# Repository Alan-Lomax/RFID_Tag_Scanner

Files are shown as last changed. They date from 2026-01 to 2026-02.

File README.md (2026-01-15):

# RFID_Tag_Scanner
This is a self contained "appliance" that can be used for testing ISO15693 RFID tags and optionally
subscribing to an MQTT broker to monitor any published messages (which might not be RFID related).

RFID input is via a PN5180-NFC scanner board. Output is via a color TFT screen (Output is also mirrored on a web page).
For Initial setup this device sets up its own Access Point hotspot. 
Pointing a web browser at it allows for it to be configured further. (see readme for details)

## Parts List (one of each):
ESP32 DevKit 1 case  .... plus 
2.8 inch TFT angled display box   ... plus 
PN5180-nfc   RFID tag reader board

## Usage
In use RFID tags can be placed on top and the LCD screen will indicate the tag details.

## 3-D Printed Project Box
This is a mash up of several 3D designs. When assembled it makes a desktop box that houses
an ESP32 in a compartment accessed from the bottom, a 2.8 inch color LCD screen in a front bezel,
and a PN5180 RFID scanner module hidden behind a top mounted cover plate.
All other wiring is contained in the box and only the USB connector is available as an external connection (for power). 

### The constituent designs used:
2.8" TFT ili9341 SPI Case     https://www.thingiverse.com/thing:3461768
ESP32 DevKit V1 Case (Thick)  https://www.thingiverse.com/thing:4609596

## 3D Case parts
Print one of each:
- Item 1 the modified box structure c/w ESP compartment        01 RFID_Scanner_RGB_Box_R0.6.stl
- Item 2 the unmodified LCD lid                                02 TFT_RGB_LCD_28_FRONT.STL
- Item 4 the lid for the ESP32 holder compartment in item 1    04 ESP32_Case_Lid

## And choose one of these to Print 
- Item 3a the modified LCD Lid adapted to mount the PN5180-NFC 03 PN5180-NFC_Cover.stl
- Item 3b An alternate for top mounting the PN5180-NFC         03b PN5180-NFC_Cover_TopMount.stl

# Print Notes:
The main box takes several hours to print. It has designed in supports that are easy to break away.
It is to be printed with the ESP cavity down against the print bed. (the top and front are open).
The other parts are less than an hour each to print and must be printed flat to the print bed.

The easy method for the PN5180-NFC is to attach it with hot glue to the top of the lid using the TopMount version of the lid.
The wires will protrude through the slot and down into the box.

Alternatively the original lid (03 PN5180-NFC_Cover.stl) for the PN5180-NFC has no openings and the PCB will mount
on the inside  of this lid ((again hot glue recommended but screws are also possible.)                 

That lid then attaches to the top of the box using 4 screws (3x10 mm)
The  LCD is 'sandwhiched' between the frony bezel and the box using 4 screws (3x10 mm)

## Wiring:
I used simple dupont F-F connectors.
The wiring could be done individually or in groups according to what you have on hand.
I had a 1o pin F-F cable and used that as a basis. At one end the 10 pin housing was kept 'stock' (LCD end) 
and at the other end the individual wires were removed and reinserted to change thw wire order.
Beyond that individual or multipin dupont housings were used according to what was on hand.
Wire Splices:
There are 4 signals that need splicing, one is 3.3 volt power and the other 3 are to do with SPI communications.

The 3.3volt output from the ESP32 needs to be split into 3 different wires, one goes to the 3 volt supply on the LCD, another 
goes to the backlight LED supply on the LCD, and the third goes to the 3.3 volt supply pin on the PN5180-NFC.
 
Because the SPI interface is used for both the LCD display and the PN5180-nfc the three wires
the three SPI wires (Clock, MISO, and MOSI) need to be split with one going to the LCD, and one to the RFID scanner board.

## Caution:
When sitting on the desk excessive downward presssure can activiate the reset button on the ESP32
You could elect to break away the cover over the reset button - making it a recessed button not subject to accidental activation.

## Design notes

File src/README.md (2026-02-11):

# MQTT RFID Reader/Display - ESP32 Version

Complete MQTT-enabled RFID reader with TFT display for ESP32.

## Version 1.0.15 - Production Ready

Optimized for RFID tag range testing with fast, responsive scanning and flicker-free display updates.

**Key Features:**
- **Fast scanning**: 250ms scan interval (4 scans/second)
- **Responsive display**: 500ms update rate with selective region updates (no flicker)
- **Quick detection**: Tag presence/removal detected within 500ms-1000ms
- **Modular architecture**: Clean separation of concerns across focused modules
- **Web configuration**: Easy setup via browser interface
- **MQTT integration**: Real-time tag event publishing
- **Security**: WiFi password protection, documented security considerations

**Core Modules:**
- `MQTTTagReaderDisplay_ESP32.ino` - Main application & coordination
- `nfc_reader.cpp/h` - PN5180 NFC interface (ISO15693 only)
- `display.cpp/h` - ILI9341 TFT display management (flicker-free updates)
- `web_server.cpp/h` - HTTP interface & configuration pages
- `mqtt_handler.cpp/h` - MQTT publishing & subscription
- `ILI9341_Landscape.h` - Custom landscape display class

## Hardware Requirements

- **ESP32** (WROOM-32 or compatible DevKit board)
- **PN5180 NFC Reader** (ISO15693/SLIX2 compatible)
- **ILI9341 TFT Display** (240x320, 2.8" or 3.2")
- Jumper wires
- USB cable for programming
- 3.3V and 5V power (from ESP32)

## Wiring

### PN5180 NFC Reader
```
PN5180 Pin    ESP32 Pin      Wire Color
-------------------------------------------
NSS (CS)   →  GPIO 5  (D5)   Orange
BUSY       →  GPIO 21 (D21)  Blue
RST        →  GPIO 22 (D22)  White
MOSI       →  GPIO 23 (D23)  Green
MISO       →  GPIO 19 (D19)  Purple
SCK        →  GPIO 18 (D18)  Brown
3.3V       →  3V3            Red
5V         →  VIN            ** CRITICAL! **
GND        →  GND            Black
```

**IMPORTANT:** The PN5180 needs **5V on the TVDD pin** (via the 5V/VIN connection) for the RF transmitter to work properly. The 3.3V connection powers the digital section.

For more information see: https://easyelecmodule.com/pn5180-explained-the-ultimate-nfc-module-with-full-protocol-compatibility/

### ILI9341 TFT Display
```
Display Pin   ESP32 Pin
---------------------------
CS         →  GPIO 15 (D15)
RST        →  GPIO 4  (D4)
DC         →  GPIO 2  (D2)
MOSI       →  GPIO 23 (D23) - shared with PN5180
MISO       →  GPIO 19 (D19) - shared with PN5180
SCK        →  GPIO 18 (D18) - shared with PN5180
VCC        →  3V3
GND        →  GND
LED        →  3V3 (or PWM pin for brightness control)
```

## Library Requirements

Install these libraries via Arduino Library Manager:

1. **PN5180 Library** by tueddy
   - GitHub: https://github.com/tueddy/PN5180-Library
   - Download ZIP and install via: Sketch → Include Library → Add .ZIP Library

2. **Adafruit GFX Library**
   - Tools → Manage Libraries → Search "Adafruit GFX"

3. **Adafruit ILI9341**
   - Tools → Manage Libraries → Search "Adafruit ILI9341"

4. **PubSubClient** (MQTT)
   - Tools → Manage Libraries → Search "PubSubClient"

5. **ArduinoJson**
   - Tools → Manage Libraries → Search "ArduinoJson"

## Arduino IDE Setup

1. **Install ESP32 Board Support:**
   - File → Preferences
   - Additional Board Manager URLs: 
     ```
     https://dl.espressif.com/dl/package_esp32_index.json
     ```
   - Tools → Board → Boards Manager
   - Search "ESP32" → Install "ESP32 by Espressif Systems"

2. **Select Board:**
   - Tools → Board → ESP32 Arduino → "ESP32 Dev Module"

3. **Configure Upload Settings:**
   - Upload Speed: 921600
   - Flash Frequency: 80MHz
   - Partition Scheme: "Default 4MB with spiffs"

## Configuration

### First Boot

1. Power on the ESP32
2. Look for WiFi network named `ESP32-RFID-ReaderDisplay`
3. Connect to it with your phone/computer
4. Browser will open automatically, or go to: `192.168.4.1`
5. Enter your WiFi credentials and MQTT broker details

### Web Interface

After WiFi is configured, access the web interface at: `http://[device-ip]/`

**Pages:**
- `/` - Main status page (tag detection, statistics, MQTT history)
- `/config` - Configuration page (WiFi password not exposed)
- `/status` - JSON API endpoint

### Configuration Options

**WiFi Settings:**
- SSID: Your WiFi network name
- Password: WiFi password (stored securely, not displayed in web interface)

**MQTT Settings:**
- Broker: IP address of your MQTT broker
- Port: Usually 1883
- Base Topic: Base topic for all messages (default: `rfid`)
- Subscribe Topic: Topic pattern to receive messages (default: `rfid/#`)
- Sensor ID: Unique ID for this reader (1-255)

**Topics Published:**
- `[base]/Read` - When tag is first detected
- `[base]/Unread` - When tag is removed
- `[base]/Continuing` - Published once when tag remains present (after 3 seconds)

**Message Format (JSON - shortened field names):**
```json
{
  "u": "E004010918485391",
  "s": 33,
  "R": "R"
}
```
- `u` = UID
- `s` = sensor_id
- `R` = direction (R=Read, C=Continuing, U=Unread)

## Usage

### Normal Operation

1. Power on device
2. Display shows "Scanning..."
3. Place ISO15693 tag on PN5180 antenna
4. Display shows "TAG PRESENT" with UID
5. MQTT message published to configured topics
6. Remove tag to generate "Unread" event

### Display Information

**Upper Section - Local Tag Scanner:**
- Current tag status (Scanning... or Local Tag Read)
- Tag UID when present (16 characters)

**Middle Section - MQTT Broker Messages:**
- Last 4 MQTT messages from any sensor
- Color-coded by event type: Green (Read), Yellow (Continuing), Red (Unread)
- Shows sensor ID, UID, and direction

**Lower Section - Status:**
- Configuration URL
- PN5180 status, version, and protocol
- Scan statistics (Scans, OK, Fail counts with real-time updates)
- MQTT connection status and broker info
- Topic configuration

**Display Features:**
- Flicker-free updates (selective region redrawing)
- Fast refresh rate (500ms)
- Left-justified welcome screen
- Streamlined WiFi connection status

## Troubleshooting

### PN5180 Not Detecting Tags

**Check wiring:**
- Verify all SPI connections (MOSI, MISO, SCK)
- **Ensure 5V is connected to VIN** (CRITICAL!)
- NSS on GPIO 5
- BUSY on GPIO 21
- RST on GPIO 22

**Verify power:**
- Measure 3.3V on PN5180 3.3V pin
- Measure 5V on PN5180 5V pin
- Both should be present simultaneously

**Test tags:**
- Use ISO15693 compatible tags (SLIX, SLIX2, I-CODE, etc.)
- Some generic tags may not work
- Try multiple tags to rule out tag issues

### Display Not Working

- Check CS pin (GPIO 15)
- Verify DC pin (GPIO 2)
- Check RST pin (GPIO 4)
- Ensure shared SPI pins are correct
- Try different display rotation: `tft.setRotation(1)` or `tft.setRotation(3)`

### WiFi Connection Issues

- Device creates AP named `ESP32-RFID-ReaderDisplay`
- Connect and configure via 192.168.4.1
- Check credentials carefully
- 2.4GHz WiFi only (ESP32 doesn't support 5GHz)

### MQTT Not Connecting

- Verify broker IP address is correct
- Check port (default 1883)
- Ensure broker accepts connections from this IP
- Check firewall settings
- Monitor MQTT broker logs

### Compilation Errors

**"PN5180.h: No such file"**
- Install tueddy's PN5180 library from GitHub

**"Adafruit_ILI9341.h: No such file"**
- Install Adafruit ILI9341 library via Library Manager

**"PubSubClient.h: No such file"**
- Install PubSubClient library via Library Manager

## Serial Monitor Debug

Connect via USB and open Serial Monitor (115200 baud) to see:
- Initialization status
- Tag detection events
- MQTT connection status
- Configuration details
- Error messages

## Performance

- **Scan Rate:** 250ms per scan (4 scans/second)
- **Tag Detection:** ~500ms (requires 2 consecutive reads for noise filtering)
- **Tag Removal:** ~1000ms timeout (4 missed scans)
- **Display Update:** Every 500ms (flicker-free selective updates)
- **MQTT Publish:** <100ms per message

**Optimized for Range Testing:**
The fast scan and display rates make this ideal for sliding RFID tags on a jig to determine detection range boundaries with precision.

## Known Issues & Limitations

1. **PN5180 requires 5V on TVDD** - Without this, RF transmitter won't work
2. **ISO15693 only** - ISO14443 (MIFARE) tags not currently supported
3. **Single tag detection** - Anti-collision not implemented
4. **No MQTT encryption** - Messages sent in plain text (see SECURITY.md)
5. **No web authentication** - Web interface accessible to anyone on network (see SECURITY.md)

**See SECURITY.md for security considerations and mitigation strategies.**

## Technical Details

### Critical PN5180 Setup

The PN5180 initialization sequence is critical:

```cpp
nfc.begin();        // Initialize SPI
nfc.reset();        // Reset chip
nfc.setupRF();      // Configure for ISO15693

// Then in loop:
nfc.getInventory(uid);  // Just scan, no reset/setupRF!
```

**DO NOT** call `reset()` or `setupRF()` in the loop - only in setup()!

### Power Requirements

- ESP32: ~240mA typical
- PN5180: ~150mA during RF transmission (from 5V rail)
- Display: ~100mA with backlight
- **Total:** ~500mA minimum

Use a quality USB power supply capable of delivering at least 1A.

## Important Files

- **README.md** - This file (setup, wiring, troubleshooting)
- **SECURITY.md** - Security considerations and best practices
- **REFACTORING_SUMMARY.md** - Details on modular architecture

## Support

For issues, check:
1. **README.md** - Wiring diagram and basic troubleshooting
2. **SECURITY.md** - Security considerations for your deployment
3. Serial Monitor output (115200 baud) for error messages
4. Web interface `/status` endpoint for diagnostics

**Common Issues:**
- Tags not detected → Check 5V connection to PN5180 VIN
- Display flickering → Already fixed in v1.0.5+
- Slow response → Update to v1.0.8+ for fast scanning
- WiFi password exposed → Fixed in v1.0.15

## License

MIT License - Free to use and modify

## Version History

### 1.0.15 - Security & Final Polish (Current)
- **Security Fix:** WiFi password no longer exposed in web interface HTML
- Added SECURITY.md with vulnerability assessment and mitigation strategies
- Password field now uses placeholder instead of displaying actual password

### 1.0.14 - MQTT Optimization
- Fixed redundant "Continuing" messages - only published once per continuous detection
- Added last event tracking to prevent MQTT spam

### 1.0.13 - Continuing Messages
- Fixed callback logic to enable "Continuing" message publishing
- Callback now triggered on every scan when tag is present

### 1.0.12 - MQTT Display Updates
- Fixed MQTT history display not updating when buffer full
- Implemented sequence counter for reliable change detection
- MQTT messages now update display within 500ms

### 1.0.11 - Display Spacing
- Adjusted scan statistics number positioning (+6 pixels right)
- Improved visual spacing between colons and values

### 1.0.10 - Tag Removal Responsiveness
- Reduced TAG_TIMEOUT from 3000ms to 1000ms
- Tag removal now detected within 1 second (4 missed scans)
- Added comprehensive timing documentation

### 1.0.9 - Display Responsiveness
- Reduced display update interval from 2000ms to 500ms (4x faster)
- Display now updates every 500ms for immediate visual feedback
- Added timing configuration documentation

### 1.0.8 - Scan Speed Optimization
- Reduced scan interval from 500ms to 250ms (2x faster)
- Now scans 4 times per second for precise range testing

### 1.0.7 - Display Polish
- Streamlined WiFi boot sequence (single page, updates in place)
- Left-justified welcome screen for cleaner appearance
- Improved label positioning on scan statistics line

### 1.0.6 - Granular Display Updates
- Ultra-smooth scan statistics updates (numbers only, no flicker)
- Only redraws changed number fields, not entire status line

### 1.0.5 - Flicker-Free Display
- Implemented selective region updates (no more full screen redraws)
- Smart change detection for each display section
- Dramatically improved visual experience

### 1.0.4 - Spurious Detection Filter
- Implemented consecutive read requirement (2 reads minimum)
- Added robust filtering for false positive detections
- Eliminated ghost tag detection issues

### 1.0.3 - Ghost Tag Fix
- Fixed spurious tag readings when no tag present
- Enhanced UID validation (reject all-zeros and all-FF patterns)
- Added debounce logic for tag return detection

### 1.0.2 - Boot Stability
- Fixed spurious tag detection on boot with no tag present
- Added UID validation before processing

### 1.0.1 - Modular Architecture
- Separated web server functionality into web_server module
- Separated MQTT handling into mqtt_handler module
- Simplified main INO file for better maintainability
- ISO15693 single-protocol focus

### 1.0.0 - Initial Baseline
- ISO15693 scanning with PN5180
- Web interface with status and configuration
- MQTT publishing: Read, Continuing, Unread events
- Stable tag detection

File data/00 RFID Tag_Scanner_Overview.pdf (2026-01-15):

# RFID Tag Scanner

Alan Lomax (M8640)
MERG RFID Special Interest Group

Zoom Meeting #29

## Block Diagram

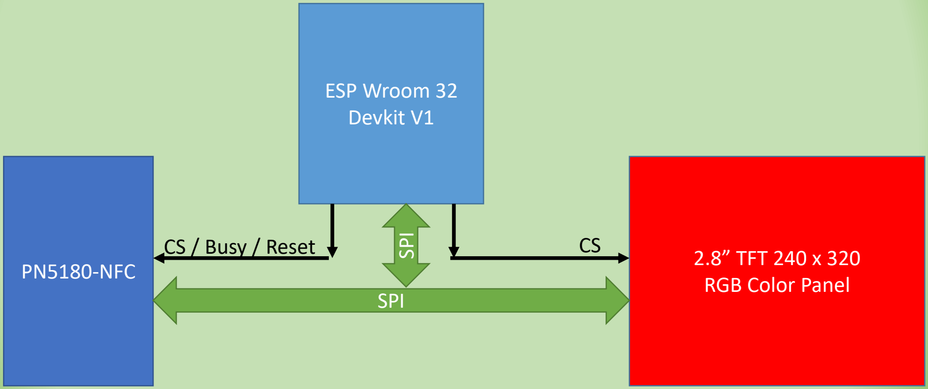
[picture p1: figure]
PN5180-NFC; ESP Wroom 32 Devkit V1; 2.8” TFT 240 x 320 RGB Color Panel; SPI; CS / Busy / Reset

## Block Diagram (Logical)

(2) Once on local WiFi unit will scan for RFID tags, update status numbers, and

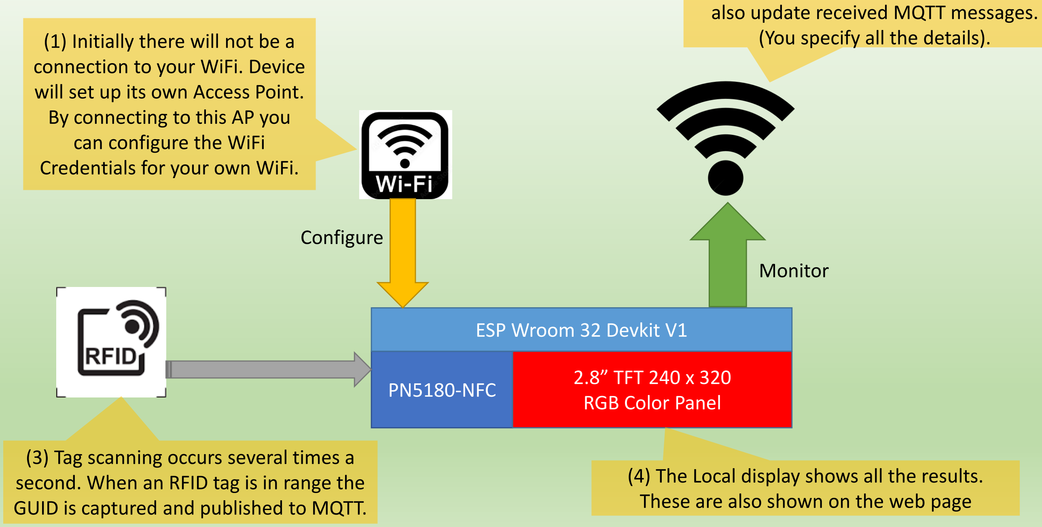
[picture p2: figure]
PN5180-NFC; ESP Wroom 32 Devkit V1; 2.8” TFT 240 x 320 RGB Color Panel; Configure; Monitor; (1) Initially there will not be a connection to your WiFi. Device will set up its own Access Point. By connecting to this AP you can configure the WiFi Credentials for your own WiFi.; also update received MQTT messages. (You specify all the details).; (3) Tag scanning occurs several times a; GUID is captured and published to MQTT.; These are also shown on the web page

second. When an RFID tag is in range the

(4) The Local display shows all the results.

## At this Moment

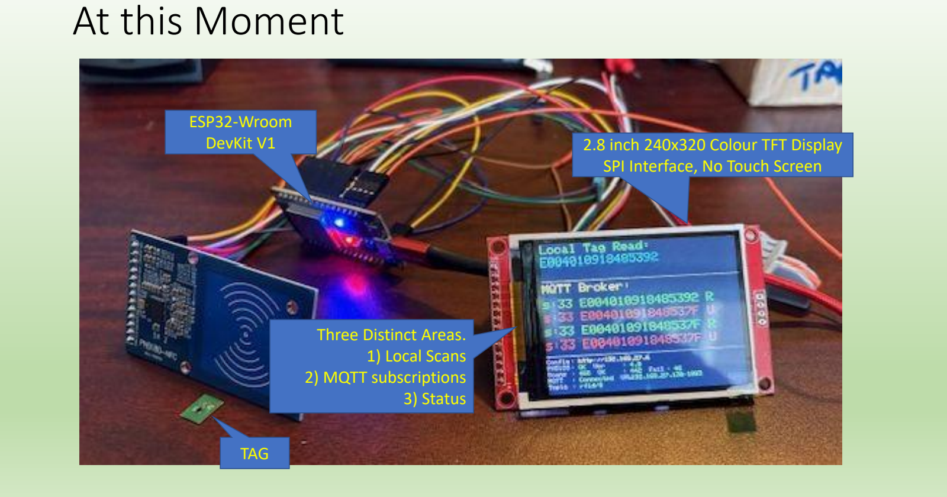
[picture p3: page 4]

TAG

PN5180-NFC

ESP32-Wroom
DevKit V1 | 2.8 inch 240x320 Colour TFT Display
| SPI Interface, No Touch Screen

Three Distinct Areas.
1) Local Scans
2) MQTT subscriptions
3) Status

## Web Interface (Main)

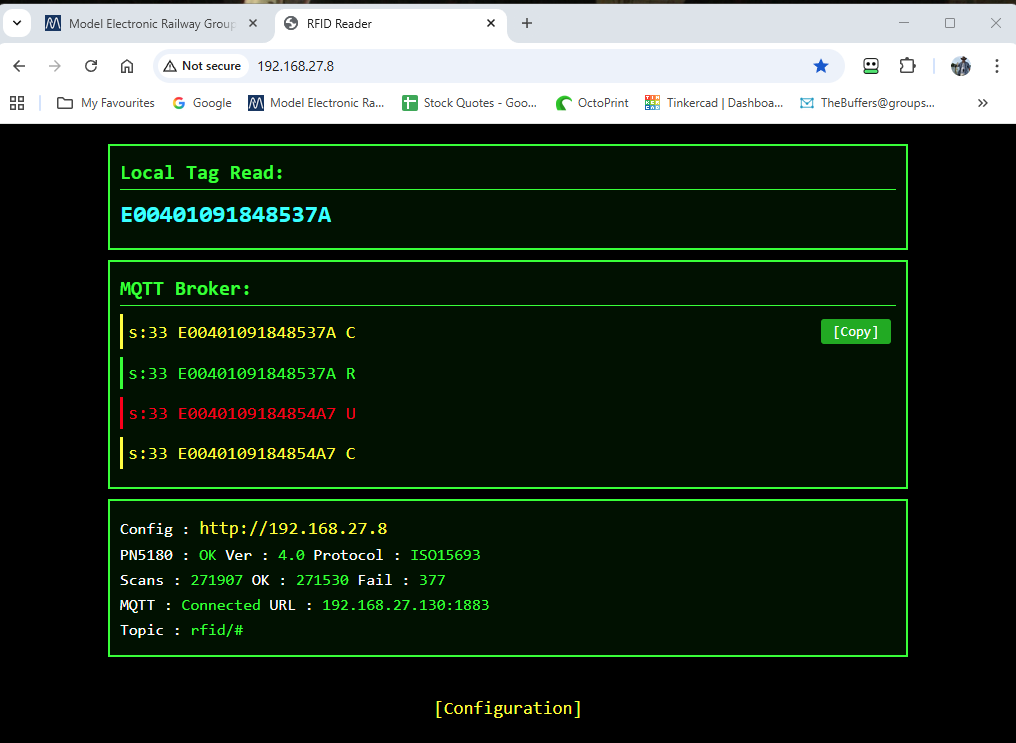
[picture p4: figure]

## Web Interface (Configuration)

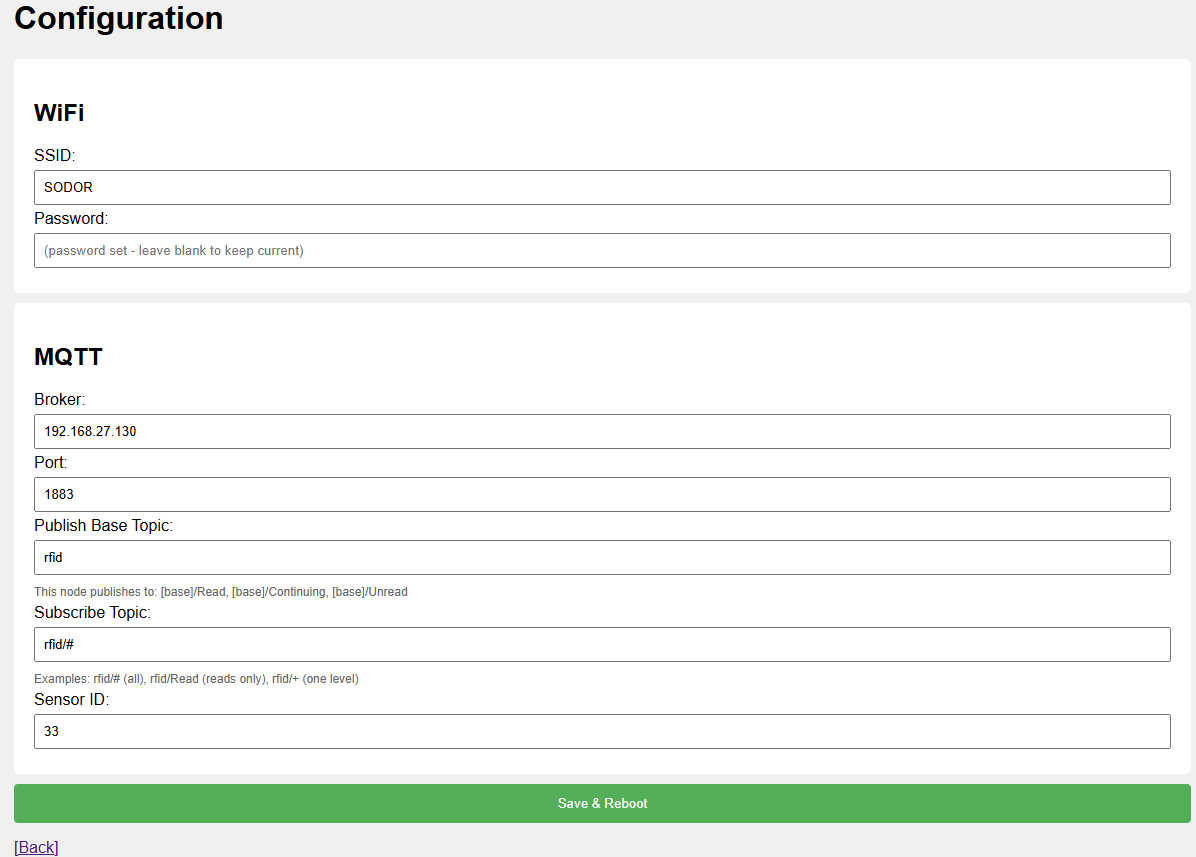
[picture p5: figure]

## Code Development

Previously I had developed a “Stock Ticker” display as an XMAS gift for my son in law. Reusable elements from this effort were expected to be:

1) ESP8266 Libraries
2) Local Display Interface Library
3) Web Interface Library
4) Initial Configuration and Remote Monitoring of Local Display
5) Saving and restoring data to and from Flash

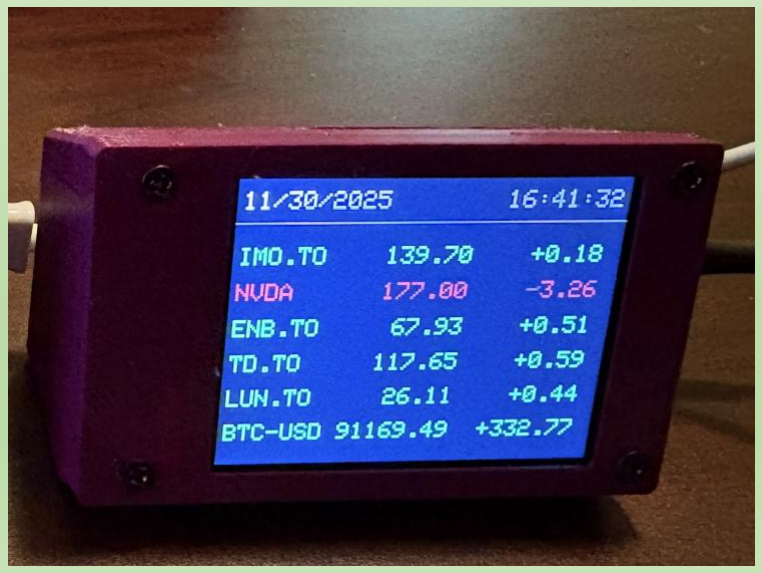
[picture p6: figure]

## Working with Claude (AI)

Reusing code from this project (provided) help me develop a well documented program for reading RFID tags using a PN5180-nfc module.
- {provide my pin assignment for this module}
- {detail how I wanted the code broken out into several modules}
- All of this was written up ahead of time (in NP++) and pasted into Claude’s window. Response was “Sure I can help you with that!”
- Needless to say it did not work first time. In fact it did not even compile
- Pasting the console output back into Claude quickly resolved compile issues. (Mostly variable scope and duplicate declarations)
- Then started working through the logic issues (Took several days).

## Summary of Issues

Hardware:
- Many internet sources claim do NOT mix 5V and 3v3 supplies on this module. Turned out to be bad advice. 5V drives the final RF amplifier. Message should have been do not mix Logic Levels (3V3 logic only)
- ESP8266 does not have enough available GPIO. (Moved to ESP32) Software
- Several libraries for this module are not fully implemented. Functions that should exist are merely stubs that return without doing anything.
- Local Display Update optimizations (flicker and update timing)
- Timing sequences when setting up scanning modes.
Logic
- “Ghost Tags” – UID’s being reported when no tags in range (cleanup).
- Scope Creep – adding features which while cool – distracted from goal

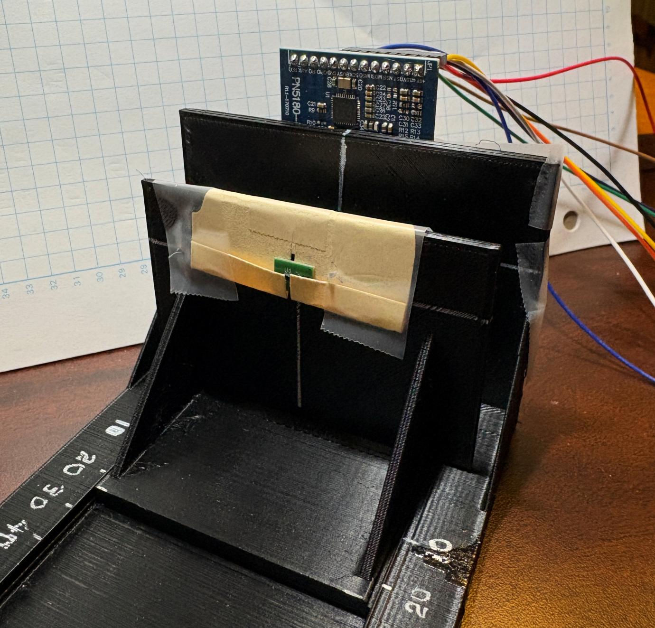
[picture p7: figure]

## In Use (Range Testing)

- Nick’s design of Test Jig
- Aerial is on fixed back plate
- Tag is on movable sled.(in pocket)
- Cross hairs for alignment
- Scale for distance
- Shown with PN5180-nfc
- Also tested SFR small aerial
- 55 tags .. Each tested twice

## 30 Second Video (Scanner In Use)

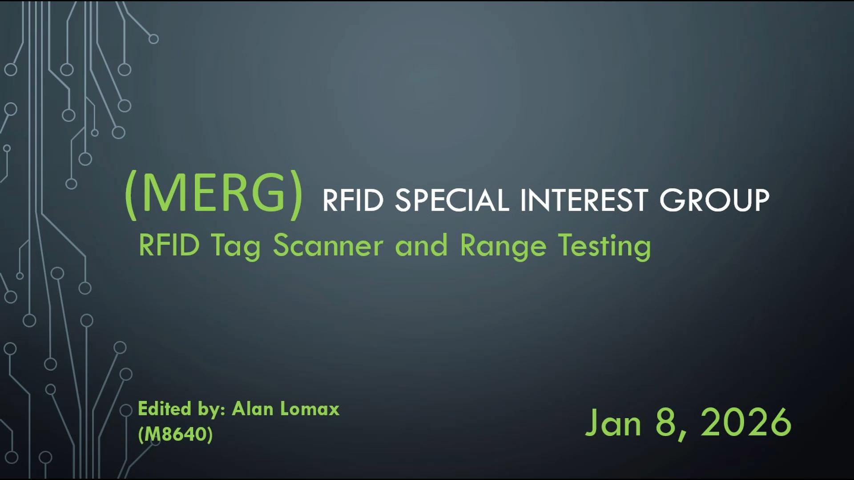
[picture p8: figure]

Play Me!

## Many Tags Were Built

Tags
- Each PCB RFID Tag was numbered (before assembly)
- Various values of matching capacitors were used
(43pF, 51pF, 53pF, 56pF, 62pF)
- Go / No-Go testing screened out defective tags (~5%) (build issues)
- Also 10 StaRFIshrail Rail ‘control’ tags were tested. (C unknown) Testing
- Drop tag into pouch on the sled part of the test jig
- Side it into and out of range. Intermittent reads did not count.
- At point where no read failures occurred the distance was recorded (along with the GUID)
After using the PN5180-nfc reader replace with a standard SFR aerial and repeat.

## Results

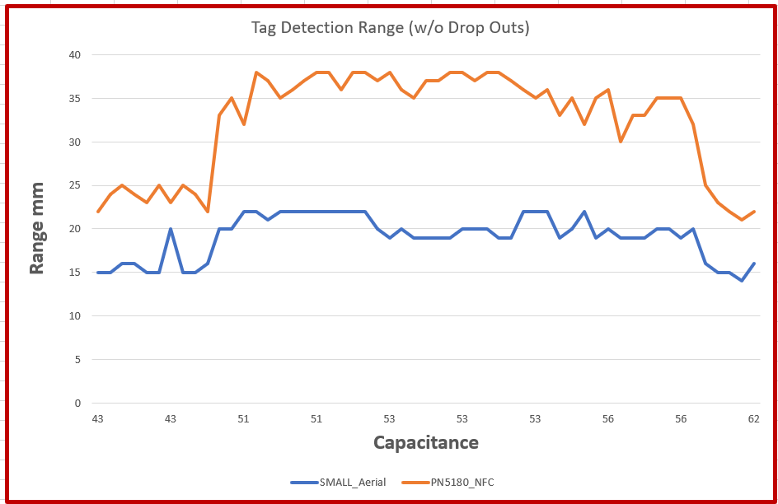
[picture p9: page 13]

# The End

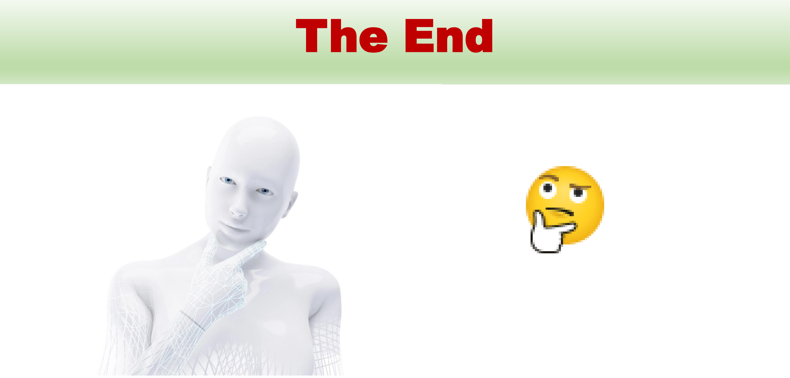
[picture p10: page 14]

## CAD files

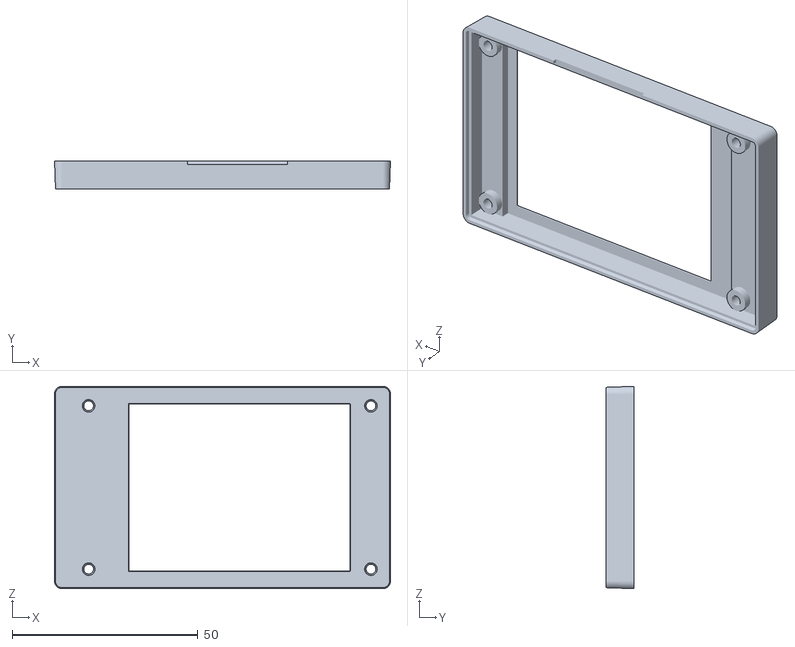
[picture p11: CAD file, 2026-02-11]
data/3D Printable Case/02 TFT_RGB_LCD_28_FRONT.STL
90.5 x 7.60 x 54.5

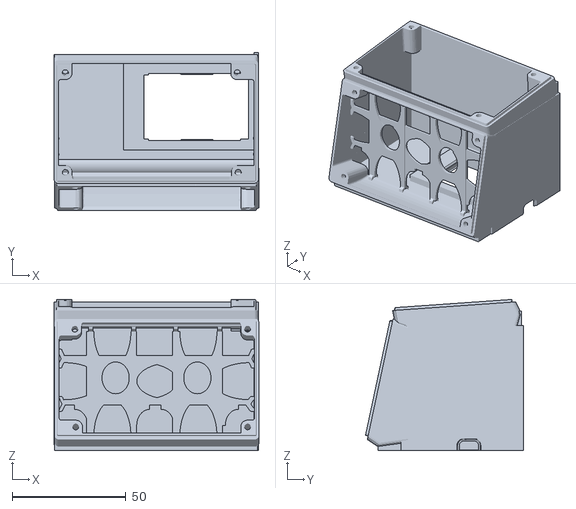
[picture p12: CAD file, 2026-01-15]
data/3D Printable Case/01 RFID_Scanner_RGB_Box_R0.6.stl
90.2 x 69.5 x 66.5

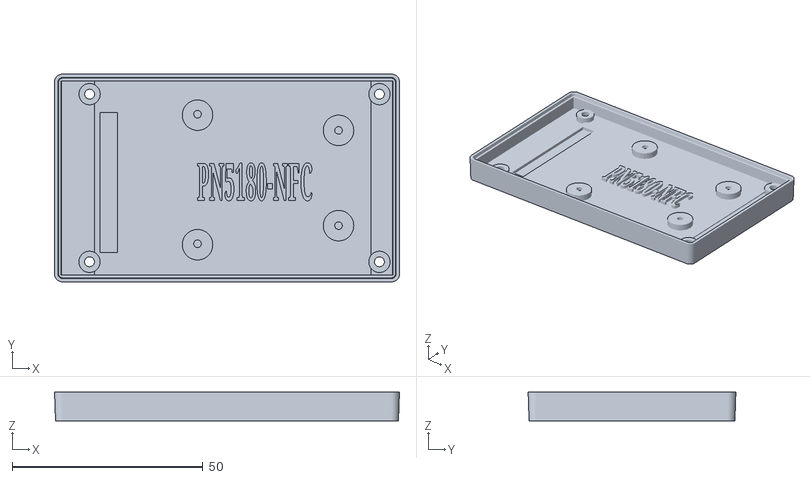
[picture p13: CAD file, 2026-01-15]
data/3D Printable Case/03 PN5180-NFC_Cover.stl
90.5 x 54.5 x 7.60

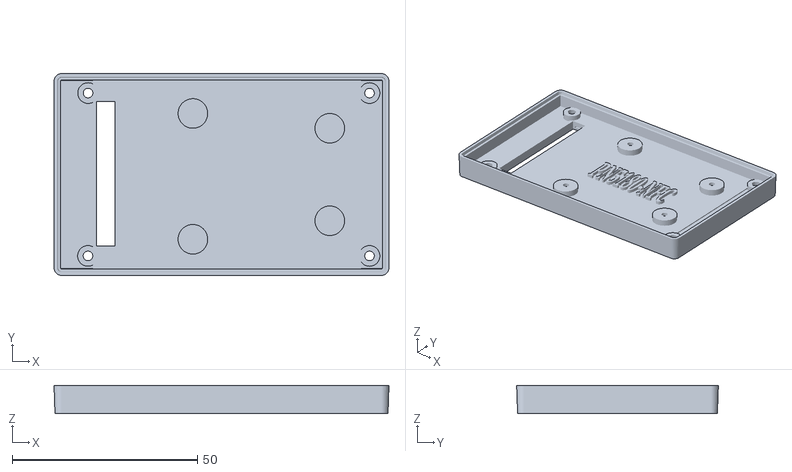
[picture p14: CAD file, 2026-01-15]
data/3D Printable Case/03b PN5180-NFC_Cover_TopMount.stl
90.5 x 54.5 x 7.60

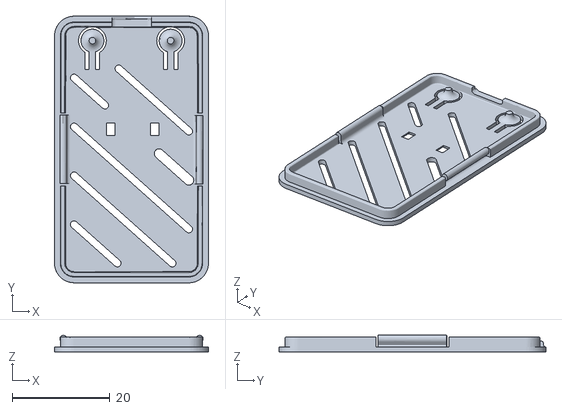
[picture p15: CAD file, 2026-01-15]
data/3D Printable Case/04 ESP32_Case_Lid.stl
31.5 x 54.6 x 3.39

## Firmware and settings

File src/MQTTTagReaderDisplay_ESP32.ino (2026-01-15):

/*
 * MQTT RFID Reader/Display - ESP32 Version (Modular)
 * 
 * ISO15693 Scanner 
 * - Looks for a Valid UID response and displays it on Local display.
 * - Also publishes to Web Page
 * - All scans published to an MQTT broker which you define.
 * 
 * Hardware:
 * - ESP32 (WROOM-32 or compatible)
 * - PN5180 NFC Reader (ISO15693)
 * - ILI9341 TFT Display (240x320)
 * 
 * See README.md for complete wiring and setup instructions
 */

#include <WiFi.h>
#include <WebServer.h>
#include <Preferences.h>
#include <PubSubClient.h>
#include <SPI.h>
#include "nfc_reader.h"
#include "display.h"
#include "web_server.h"
#include "mqtt_handler.h"

// Version Information
#define VERSION "1.0.15"
#define BUILD_DATE __DATE__
#define BUILD_TIME __TIME__
#define HOSTNAME "ESP32-RFID-ReaderDisplay"

// Timing Configuration
// =====================
// SCAN_INTERVAL (nfc_reader.h): 250ms = 4 scans/second
//   - Controls how often PN5180 checks for tags
//   - Lower = more responsive range detection
//   - Practical minimum: ~100ms (PN5180 RF field cycling)
//   - Consecutive reads required: 2 (noise filtering)
//
// TAG_TIMEOUT (nfc_reader.cpp): 1000ms
//   - How long after last detection before tag considered "removed"
//   - Should be 3-5x SCAN_INTERVAL for reliable detection
//   - Current: 4x scan interval = very responsive removal detection
//
// DISPLAY_UPDATE_INTERVAL: 500ms = 2 updates/second  
//   - Controls how often display refreshes
//   - With selective updates, can go much faster without flicker
//   - Practical minimum: ~100ms (human perception limit)
//   - Should be >= SCAN_INTERVAL for best responsiveness
//
// MQTT_RECONNECT_INTERVAL: 5000ms
//   - How often to retry MQTT connection if disconnected
//   - No need to change this
#define DISPLAY_UPDATE_INTERVAL 500
#define MQTT_RECONNECT_INTERVAL 5000

// Configuration
Config config;
Preferences preferences;

// Objects
WiFiClient espClient;
PubSubClient mqttClient(espClient);
WebServer webServer(80);

// State
unsigned long lastDisplayUpdate = 0;
unsigned long lastMqttReconnect = 0;
uint32_t mqttPublished = 0;
String lastPublishedUID = "";
String lastPublishedEvent = "";  // Track last event type (Read, Continuing, Unread)
unsigned long lastContinuingTime = 0;
#define CONTINUING_INTERVAL 3000  // Publish continuing every 3 seconds

// Forward declarations
void tagDetected(const char* uid, bool present);
void setupWiFi();
void loadConfig();
void saveConfig();

void setup() {
  Serial.begin(115200);
  delay(1000);
  
  Serial.println(F("\n================================="));
  Serial.println(F("  MQTT RFID Reader/Display"));
  Serial.print(F("  Version: ")); Serial.println(VERSION);
  Serial.print(F("  Build: ")); Serial.print(BUILD_DATE); 
  Serial.print(F(" ")); Serial.println(BUILD_TIME);
  Serial.println(F("  Platform: ESP32"));
  Serial.println(F("================================="));
  
  // Load configuration
  loadConfig();
  
  // Initialize SPI (shared between PN5180 and display)
  SPI.begin(18, 19, 23, 5);  // SCK, MISO, MOSI, SS
  Serial.println(F("SPI initialized"));
  
  // Initialize Display
  Serial.println(F("\n=== Initializing Display ==="));
  initDisplay();
  
  // Show welcome screen with version
  displayWelcome(VERSION, BUILD_DATE);
  delay(3000);  // Show for 3 seconds
  
  displayMessage("Initializing...");
  
  // Setup WiFi
  setupWiFi();
  
  // Setup MQTT
  initMqttHandler(&mqttClient, &config);
  
  // Pass broker config to display
  setMqttConfig(config.mqtt_broker, config.mqtt_port, config.mqtt_subscribe_topic);
  
  // Setup Web Server
  setWebServerConfig(&config);
  setWebServerMqttClient(&mqttClient);
  setWebServerMqttPublished(&mqttPublished);
  setConfigSaveCallback(saveConfig);
  initWebServer(&webServer);
  
  // Initialize PN5180 - CRITICAL: Only once!
  Serial.println(F("\n=== Initializing PN5180 ==="));
  displayStatus("Init NFC...");
  
  if (initNFCReader()) {
    Serial.println(F("PN5180 initialized successfully"));
    setTagCallback(tagDetected);  // Set callback for tag events
  } else {
    Serial.println(F("PN5180 initialization failed"));
    displayMessage("NFC Init Failed!");
    delay(2000);
  }
  
  Serial.println(F("\n=== Setup Complete ==="));
  displayStatus("Ready!");
  updateDisplay();
}

void loop() {
  // Handle web server
  webServer.handleClient();
  
  // Process NFC reader (scans for tags)
  processNFCReader();
  
  // Handle MQTT connection
  if (!mqttClient.connected()) {
    setMqttStatus(false);
    unsigned long now = millis();
    if (now - lastMqttReconnect > MQTT_RECONNECT_INTERVAL) {
      lastMqttReconnect = now;
      reconnectMQTT();
    }
  } else {
    setMqttStatus(true);
    mqttClient.loop();
  }
  
  // Update display periodically
  unsigned long now = millis();
  if (now - lastDisplayUpdate > DISPLAY_UPDATE_INTERVAL) {
    lastDisplayUpdate = now;
    updateDisplay();
  }
  
  yield();
}

// Tag detection callback
void tagDetected(const char* uid, bool present) {
  // Update display
  displayTag(uid, present);
  
  // Publish MQTT event
  if (present) {
    if (String(uid) != lastPublishedUID) {
      // New tag - publish Read
      publishTag(uid, "Read");
      lastPublishedUID = String(uid);
      lastPublishedEvent = "Read";
      lastContinuingTime = millis();
      mqttPublished++;
    } else {
      // Same tag still present - check if we should publish Continuing
      unsigned long now = millis();
      if (now - lastContinuingTime >= CONTINUING_INTERVAL) {
        // Only publish Continuing if the last event was NOT already Continuing
        if (lastPublishedEvent != "Continuing") {
          publishTag(uid, "Continuing");
          lastPublishedEvent = "Continuing";
          lastContinuingTime = now;
          mqttPublished++;
        }
        // If last event was already Continuing, do nothing (no spam)
      }
    }
  } else {
    // Tag removed - publish Unread
    publishTag(uid, "Unread");
    lastPublishedUID = "";
    lastPublishedEvent = "Unread";
    mqttPublished++;
  }
}

// Configuration functions
void loadConfig() {
  preferences.begin("rfid-reader", false);
  
  strlcpy(config.wifi_ssid, preferences.getString("wifi_ssid", "").c_str(), sizeof(config.wifi_ssid));
  strlcpy(config.wifi_password, preferences.getString("wifi_pass", "").c_str(), sizeof(config.wifi_password));
  strlcpy(config.mqtt_broker, preferences.getString("mqtt_broker", "192.168.1.100").c_str(), sizeof(config.mqtt_broker));
  config.mqtt_port = preferences.getUInt("mqtt_port", 1883);
  strlcpy(config.mqtt_base_topic, preferences.getString("mqtt_pub_topic", "rfid").c_str(), sizeof(config.mqtt_base_topic));
  strlcpy(config.mqtt_subscribe_topic, preferences.getString("mqtt_sub_topic", "rfid/#").c_str(), sizeof(config.mqtt_subscribe_topic));
  config.sensor_id = preferences.getUChar("sensor_id", 33);
  
  preferences.end();
  
  Serial.println(F("\n=== Configuration ==="));
  Serial.print(F("MQTT: ")); Serial.print(config.mqtt_broker); 
  Serial.print(F(":")); Serial.println(config.mqtt_port);
  Serial.print(F("Publish Base: ")); Serial.println(config.mqtt_base_topic);
  Serial.print(F("Subscribe: ")); Serial.println(config.mqtt_subscribe_topic);
  Serial.print(F("Sensor ID: ")); Serial.println(config.sensor_id);
}

void saveConfig() {
  preferences.begin("rfid-reader", false);
  
  preferences.putString("wifi_ssid", config.wifi_ssid);
  preferences.putString("wifi_pass", config.wifi_password);
  preferences.putString("mqtt_broker", config.mqtt_broker);
  preferences.putUInt("mqtt_port", config.mqtt_port);
  preferences.putString("mqtt_pub_topic", config.mqtt_base_topic);
  preferences.putString("mqtt_sub_topic", config.mqtt_subscribe_topic);
  preferences.putUChar("sensor_id", config.sensor_id);
  
  preferences.end();
  Serial.println(F("Configuration saved"));
}

void setupWiFi() {
  Serial.println(F("\n=== WiFi Setup ==="));
  
  WiFi.mode(WIFI_STA);
  WiFi.setHostname(HOSTNAME);
  
  if (strlen(config.wifi_ssid) > 0) {
    // Show connecting status
    displayWiFiStatus(config.wifi_ssid, IPAddress(0,0,0,0), true);
    
    Serial.print(F("Connecting to: "));
    Serial.println(config.wifi_ssid);
    
    WiFi.begin(config.wifi_ssid, config.wifi_password);
    
    int attempts = 0;
    while (WiFi.status() != WL_CONNECTED && attempts < 20) {
      delay(500);
      Serial.print(".");
      attempts++;
    }
    Serial.println();
  }
  
  if (WiFi.status() != WL_CONNECTED) {
    Serial.println(F("Starting AP mode"));
    WiFi.softAP(HOSTNAME);
    
    displayMessage("WiFi AP Mode");
    delay(1000);
    
    displayWiFiSetup();
    delay(5000);  // Show instructions for 5 seconds
    
  } else {
    Serial.println(F("WiFi connected!"));
    Serial.print(F("IP: "));
    Serial.println(WiFi.localIP());
    
    // Update same page with connected status
    displayWiFiStatus(WiFi.SSID().c_str(), WiFi.localIP(), false);
    delay(5000);  // Show IP for 5 seconds
  }
}

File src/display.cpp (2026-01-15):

/*
 * display.cpp
 * 
 * ILI9341 Display Implementation
 */

#include "display.h"
#include "ILI9341_Landscape.h"
#include "nfc_reader.h"
#include <Adafruit_GFX.h>
#include <WiFi.h>

// Global display object - using custom landscape class
static ILI9341_Landscape tft = ILI9341_Landscape(TFT_CS, TFT_DC, TFT_RST);

// Display state
static String currentUID = "";
static bool currentTagPresent = false;
static bool mqttConnected = false;

// Previous state for change detection (flicker reduction)
static String prevUID = "";
static bool prevTagPresent = false;
static bool prevMqttConnected = false;
static uint32_t prevTotalScans = 0;
static uint32_t prevSuccessfulReads = 0;
static uint32_t prevFailedReads = 0;
static bool prevNfcInitialized = false;
static bool displayInitialized = false;

// MQTT message history (up to 4 messages)
static MqttMessage mqttHistory[4];  // Struct defined in display.h
static int mqttHistoryCount = 0;
static uint32_t mqttSequence = 0;  // Sequence number - increments on every new message
static uint32_t prevMqttSequence = 0;

// MQTT broker config
static String mqttBroker = "";
static uint16_t mqttPort = 1883;
static String mqttTopic = "";

void initDisplay() {
  Serial.println(F("Initializing ILI9341 display..."));
  
  tft.begin();
  tft.setRotation(0);  // Portrait - but custom class swaps to landscape
  tft.fillScreen(COLOR_BLACK);
  tft.setTextColor(COLOR_WHITE);
  tft.setTextSize(2);
  
  Serial.print(F("Display dimensions: "));
  Serial.print(tft.width());
  Serial.print(F(" x "));
  Serial.println(tft.height());
  
  Serial.println(F("Display initialized"));
}

void displayWelcome(const char* version, const char* buildDate) {
  tft.fillScreen(COLOR_BLACK);
  
  // Title - left justified
  tft.setTextSize(3);
  tft.setTextColor(COLOR_CYAN);
  tft.setCursor(10, 40);
  tft.println("RFID");
  tft.setCursor(10, 75);
  tft.println("Reader");
  
  // Version - left justified
  tft.setTextSize(2);
  tft.setTextColor(COLOR_WHITE);
  tft.setCursor(10, 125);
  tft.print("Ver ");
  tft.println(version);
  
  // Build date - left justified
  tft.setTextSize(1);
  tft.setCursor(10, 150);
  tft.println(buildDate);
  
  // Platform - left justified
  tft.setCursor(10, 165);
  tft.setTextColor(COLOR_YELLOW);
  tft.println("ESP32 + PN5180");
}

void displayWiFiStatus(const char* ssid, IPAddress ip, bool connecting) {
  // Single page display for WiFi status - updates in place
  tft.fillScreen(COLOR_BLACK);
  
  if (connecting) {
    // Connecting state
    tft.setTextSize(2);
    tft.setTextColor(COLOR_YELLOW);
    tft.setCursor(10, 60);
    tft.println("WiFi Connecting...");
    
    tft.setTextSize(1);
    tft.setTextColor(COLOR_WHITE);
    tft.setCursor(10, 100);
    tft.print("SSID: ");
    tft.println(ssid);
  } else {
    // Connected state - replace text on same page
    tft.setTextSize(2);
    tft.setTextColor(COLOR_GREEN);
    tft.setCursor(10, 60);
    tft.println("WiFi Connected!");
    
    tft.setTextSize(1);
    tft.setTextColor(COLOR_WHITE);
    tft.setCursor(10, 100);
    tft.print("SSID: ");
    tft.println(ssid);
    
    tft.setCursor(10, 120);
    tft.setTextColor(COLOR_CYAN);
    tft.println("Configure via web browser:");
    
    tft.setTextSize(2);
    tft.setTextColor(COLOR_YELLOW);
    tft.setCursor(10, 145);
    tft.print("http://");
    tft.println(ip);
  }
}

void displayWiFiSetup() {
  tft.fillScreen(COLOR_BLACK);
  tft.setTextSize(2);
  tft.setTextColor(COLOR_YELLOW);
  tft.setCursor(10, 40);
  tft.println("WiFi Setup");
  tft.println("Required");
  
  tft.setTextSize(1);
  tft.setTextColor(COLOR_WHITE);
  tft.setCursor(10, 100);
  tft.println("1. Connect phone/PC to:");
  tft.setTextColor(COLOR_CYAN);
  tft.println("   ESP32-RFID-ReaderDisplay");
  
  tft.setTextColor(COLOR_WHITE);
  tft.setCursor(10, 140);
  tft.println("2. Browser opens automatically");
  tft.println("   or go to:");
  tft.setTextColor(COLOR_CYAN);
  tft.println("   http://192.168.4.1");
  
  tft.setTextColor(COLOR_WHITE);
  tft.setCursor(10, 195);
  tft.println("3. Enter WiFi credentials");
}

void displayIPAddress(const char* ssid, IPAddress ip) {
  tft.fillScreen(COLOR_BLACK);
  tft.setTextSize(2);
  tft.setTextColor(COLOR_GREEN);
  tft.setCursor(10, 60);
  tft.println("WiFi Connected!");
  
  tft.setTextSize(1);
  tft.setTextColor(COLOR_WHITE);
  tft.setCursor(10, 100);
  tft.print("SSID: ");
  tft.println(ssid);
  
  tft.setCursor(10, 120);
  tft.setTextColor(COLOR_CYAN);
  tft.println("Configure via web browser:");
  
  tft.setTextSize(2);
  tft.setTextColor(COLOR_YELLOW);
  tft.setCursor(10, 145);
  tft.print("http://");
  tft.println(ip);
}

void displayMessage(const char* msg) {
  tft.fillScreen(COLOR_BLACK);
  tft.setCursor(10, 100);
  tft.setTextSize(2);
  tft.setTextColor(COLOR_WHITE);
  tft.println(msg);
}

void displayStatus(const char* status) {
  // Large centered status message for initialization steps
  tft.fillScreen(COLOR_BLACK);
  tft.setTextSize(2);
  tft.setTextColor(COLOR_CYAN);
  
  // Simple centering
  int y = 100;
  tft.setCursor(10, y);
  tft.println(status);
}

void displayTag(const char* uid, bool present) {
  currentUID = String(uid);
  currentTagPresent = present;
  updateDisplay();
}

void setMqttStatus(bool connected) {
  mqttConnected = connected;
}

void setMqttConfig(const char* broker, uint16_t port, const char* topic) {
  mqttBroker = String(broker);
  mqttPort = port;
  mqttTopic = String(topic);
}

void addMqttMessage(const char* uid, uint8_t sensor, char direction) {
  // Shift history down (for 4 elements: shift 3->2, 2->1, 1->0)
  for (int i = 3; i > 0; i--) {
    mqttHistory[i] = mqttHistory[i-1];
  }
  
  // Add new message at top
  mqttHistory[0].uid = String(uid);
  mqttHistory[0].sensor = sensor;
  mqttHistory[0].direction = direction;
  mqttHistory[0].timestamp = millis();
  
  if (mqttHistoryCount < 4) mqttHistoryCount++;
  
  // Always increment sequence to trigger display update
  mqttSequence++;
  
  Serial.print(F("MQTT history count: "));
  Serial.print(mqttHistoryCount);
  Serial.print(F(", sequence: "));
  Serial.println(mqttSequence);
}

// Getter functions for web display
String getCurrentUID() {
  return currentUID;
}

bool getCurrentTagPresent() {
  return currentTagPresent;
}

int getMqttHistoryCount() {
  return mqttHistoryCount;
}

MqttMessage getMqttHistoryItem(int index) {
  if (index >= 0 && index < mqttHistoryCount) {
    return mqttHistory[index];
  }
  return MqttMessage{"", 0, ' ', 0};
}

// Helper function to clear a specific region (reduces flicker)
void clearRegion(int x, int y, int width, int height) {
  tft.fillRect(x, y, width, height, COLOR_BLACK);
}
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

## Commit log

2026-01-15 Enhance README with detailed project information
    Expanded the README to provide detailed information about the RFID Tag Scanner, including parts list, usage instructions, 3D printed project box details, print notes, wiring instructions, and caution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
2026-01-15 Add files via upload
    Initial
    [01 RFID_Scanner_RGB_Box_R0.6.stl, 02 TFT_RGB_LCD_28_FRONT.STL, 03 PN5180-NFC_Cover.stl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]
2026-02-11 General Update
    Added quality of reads bar graph
    [01 RFID_Scanner_RGB_Box_R0.6.stl, 02 TFT_RGB_LCD_28_FRONT.STL, 03 PN5180-NFC_Cover.stl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]
